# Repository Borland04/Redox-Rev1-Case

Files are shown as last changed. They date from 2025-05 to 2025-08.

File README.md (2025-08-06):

# Case for a Wireless Redox Rev1 Keyboard

Case for a [Redox keyboard](https://github.com/mattdibi/redox-keyboard/tree/master/redox) with Wristrest and Tenting, built from scratch but inspired by [Original Mattdibi Case](https://github.com/mattdibi/redox-keyboard/tree/master/redox/case), [Neodox Case](https://github.com/Pastitas/Redox-neo-Case) and [Ergodox Keyboard](https://ergodox-ez.com/).

This case is built for a **Wireless** Rev1 with use of [Nice!Nano V2](https://nicekeyboards.com/nice-nano/) MCU (Or its alternatives. In my case - [ProMicro NRF52840](https://www.elecrow.com/pro-micro-nrf52840-development-board-compatible-with-nice-nano-v2-0.html)).

**TL;DR:** [Assembly Guide](#assembly)

## Table of Contents
* [Bill of Materials](#bill-of-materials)
* [PCB Prerequisites](#pcb-prerequisites)
  * [Differences & Requirements](#differences--requirements)
* [Assembly](#assembly)
  * [Bottom](#bottom)
  * [Top](#top)
  * [Tenting](#tenting)
  * [Wrist Rest](#wrist-rest)
  * [Final Touches](#final-touches)
* [Contributions](#contributions)
* [To Be Done](#to-be-done)

---

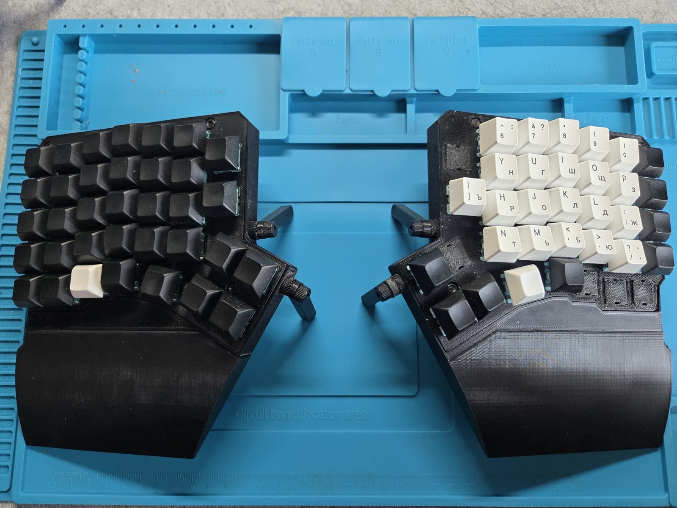
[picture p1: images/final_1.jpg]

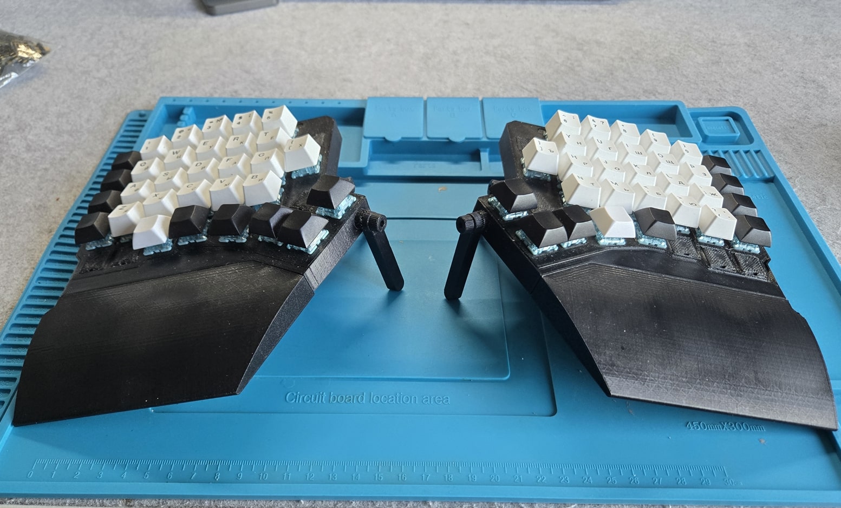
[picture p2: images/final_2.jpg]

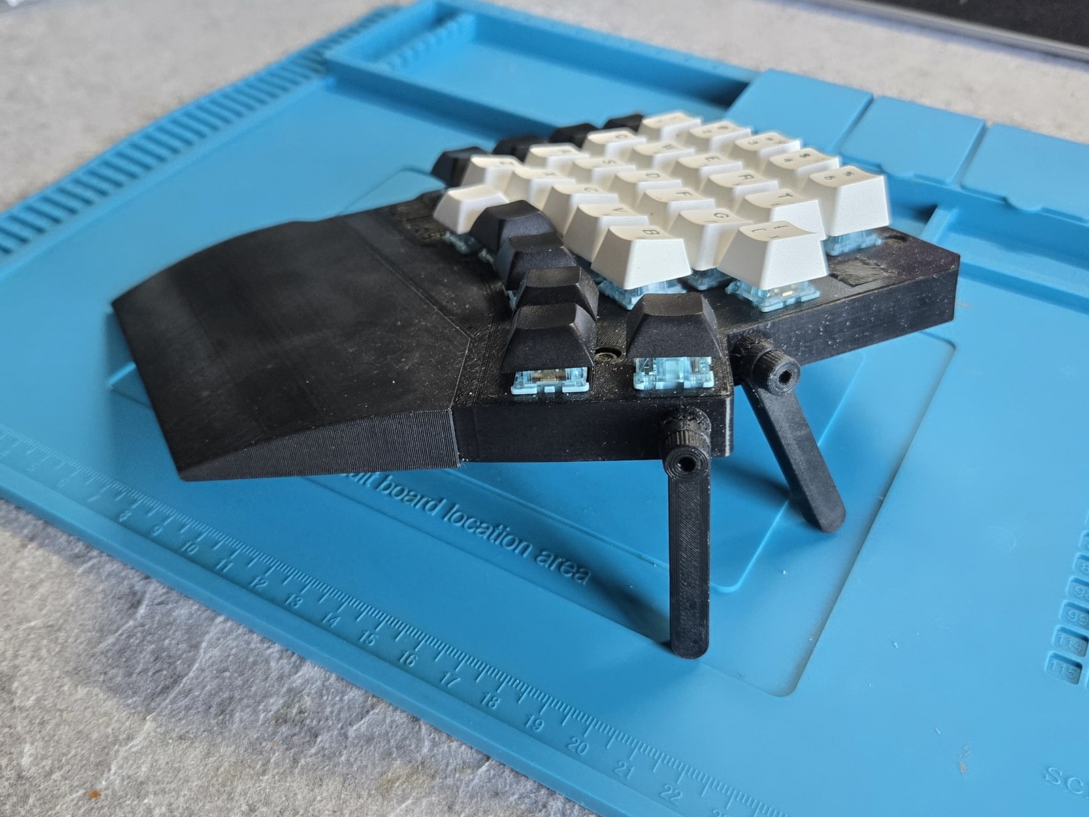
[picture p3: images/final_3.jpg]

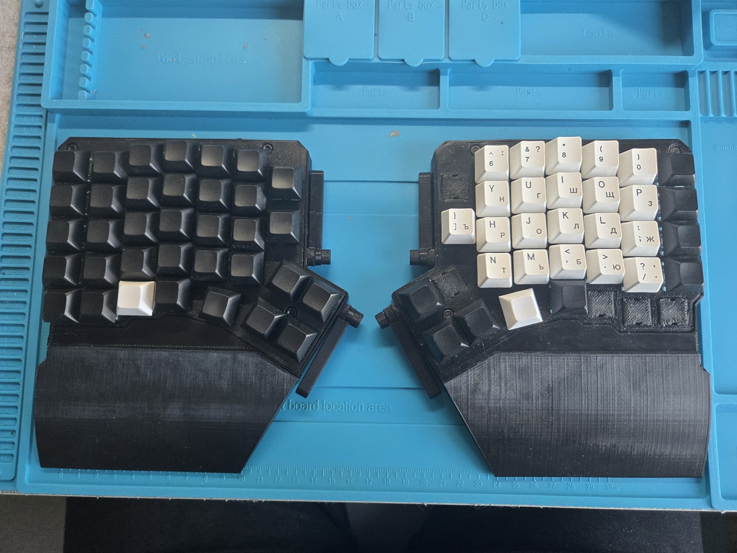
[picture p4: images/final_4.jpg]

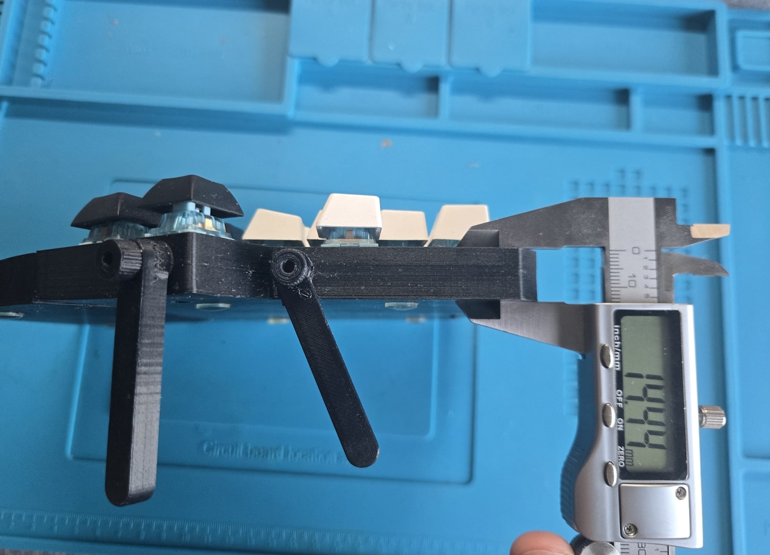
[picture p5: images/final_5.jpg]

> [!WARNING]
> +2mm if using `bottom_8mm` (which is preferred, because of right half's USB position. See [Assembly Guide](#assembly) for more info)

---
## Bill of Materials

| Item | Image | Quantity | Description |
| --- | --- | --- | --- |
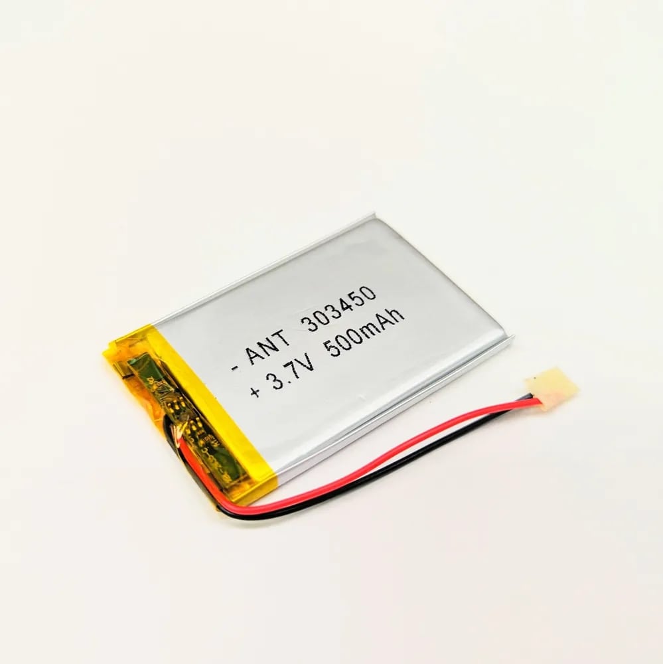
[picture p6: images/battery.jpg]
| LiPol 3.7V Battery 403040 or thinner (500 mAh). Might be thicker if using `bottom_8mm` |  | 2 | |
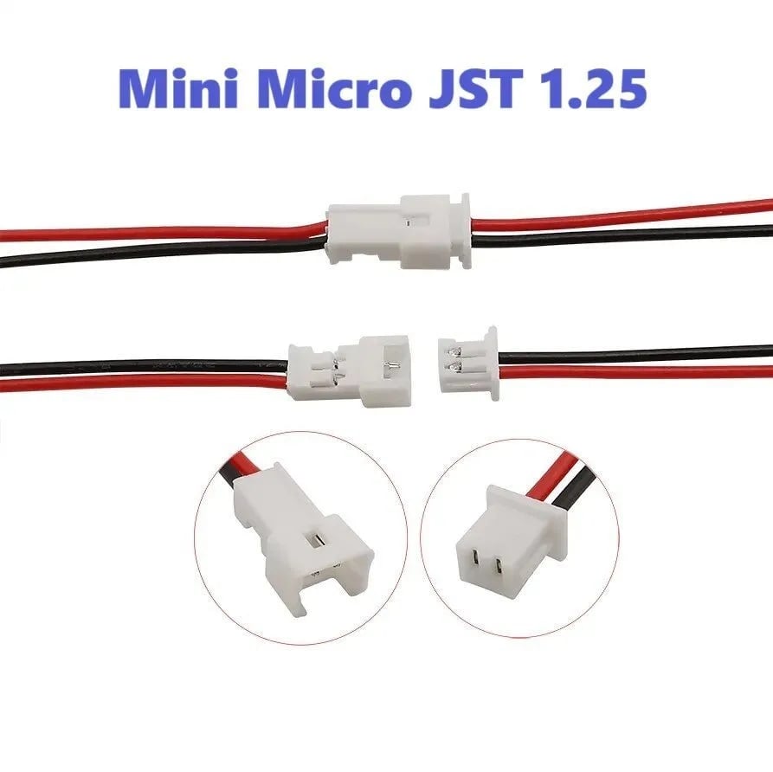
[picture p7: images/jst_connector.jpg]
| JST-XH PH 1,25 2-pin connectors |  | 2 pairs | Used to connect batteries to a PCBs<br><br>Part of a `PCB Prerequisites` |
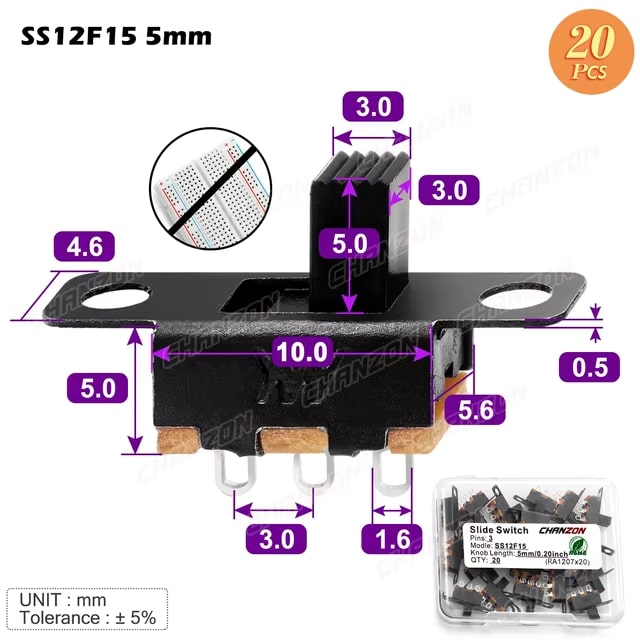
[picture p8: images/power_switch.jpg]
| Micro Slide Switch Spdt SS12F15 |  | 2 | [AliExpress](https://aliexpress.ru/item/1005003938856402.html?sku_id=12000027515454290)<br><br>Part of a `PCB Prerequisites` |
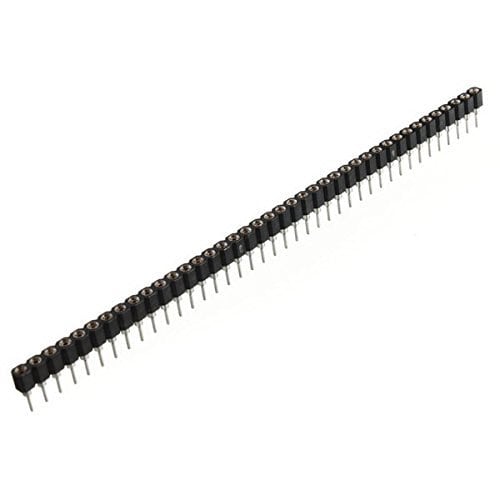
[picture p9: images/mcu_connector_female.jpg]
| MCU Hot-Swap Female connector |  | 48 pins | [Amazon](https://www.amazon.in/Single-Headers-Machine-Female-2-54mm/dp/B0187LTEX2)<br><br>Part of a `PCB Prerequisites` |
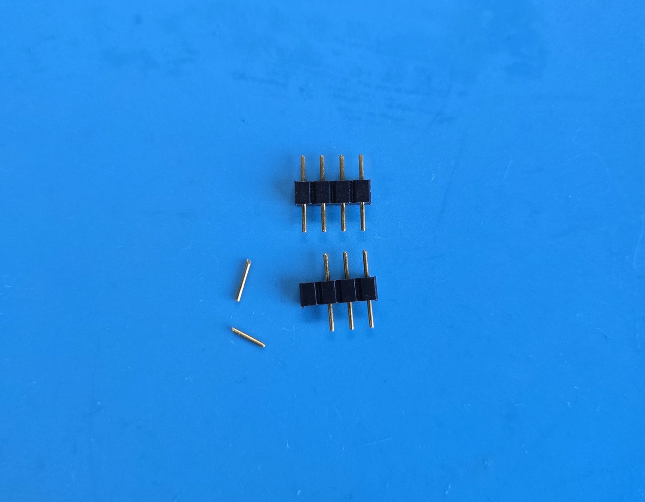
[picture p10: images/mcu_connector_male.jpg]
| RGB 4-pin Male connector<br> |  | 24 pins | [AliExpress](https://aliexpress.ru/item/1005006655092258.html?gatewayAdapt=glo2rus&sku_id=12000037934700782)<br>Remove plastic holder, cut each pin in two halves<br><br>Part of a `PCB Prerequisites` |
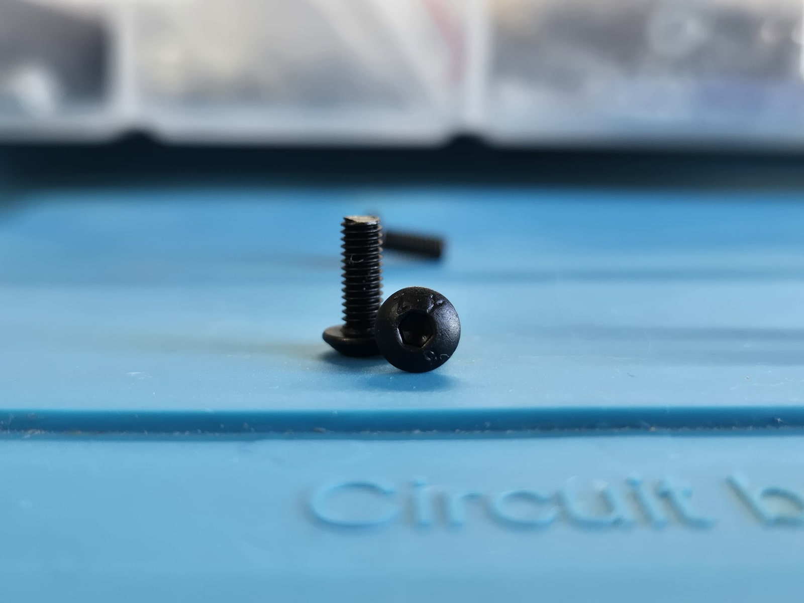
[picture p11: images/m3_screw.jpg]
| M3x8 Screw<br> |  | 12 | Used in a tight space. Use Hex or Phillips screws. Do not use screws made for a wrench. |
| M3x2.5 Nut | | 12 (14 with Wrist Rest) | |
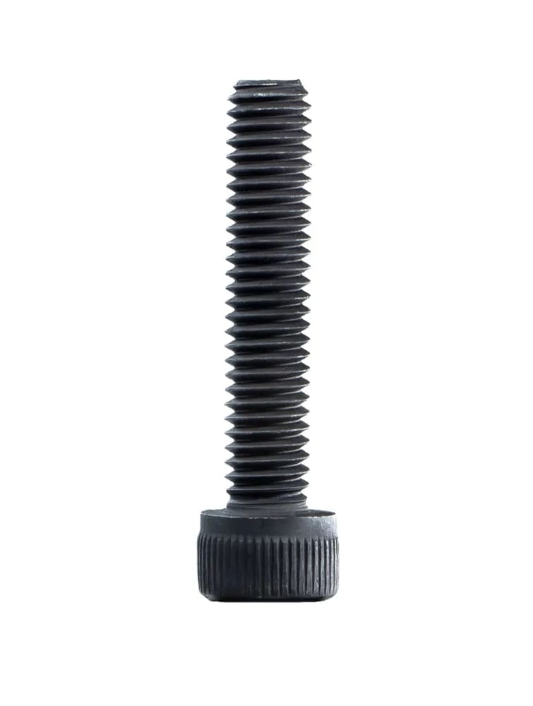
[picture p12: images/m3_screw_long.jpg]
| M3x16 Screw<br> |  | 0 (2 with Wrist Rest) | Used only in a Wrist Rest |
| M2 Nut | | 2 | Used to fix Power Switch |
| M2x4 Screw | | 2 | Used to fix Power Switch. Can be longer. |
| Hot Glue | | - | Need a few places, to fix some elements. Can be done without it, but not recommended. |
| Silicon pads 9x1.5 (Or thicker if you want) | | 8 (12 with Wrist Rest)  | |

## PCB Prerequisites

> [!WARNING]
> Guide below assumes you have assembled PCB.
> This section describes how my PCB looked like when I did assemble the case.
> Minor differences should be fine, but case was only tested with described PCB.

Original PCB assembly guide: https://github.com/mattdibi/redox-keyboard/tree/master/redox#assembly-guide

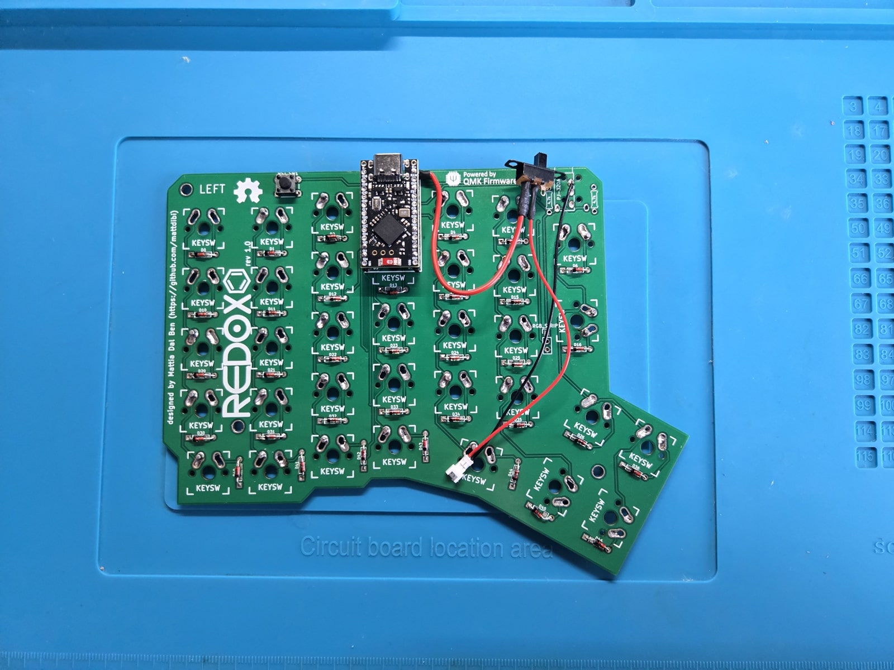
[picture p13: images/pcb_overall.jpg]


---

#### Differences & Requirements:

* PCB must have Hot-Swappable switches (see https://github.com/mattdibi/redox-keyboard/tree/master/redox#hot-swappable-switches) - required by `Top` part of the case. *You can workaround this requirement by extending "switch holes" on a `Top` part* 

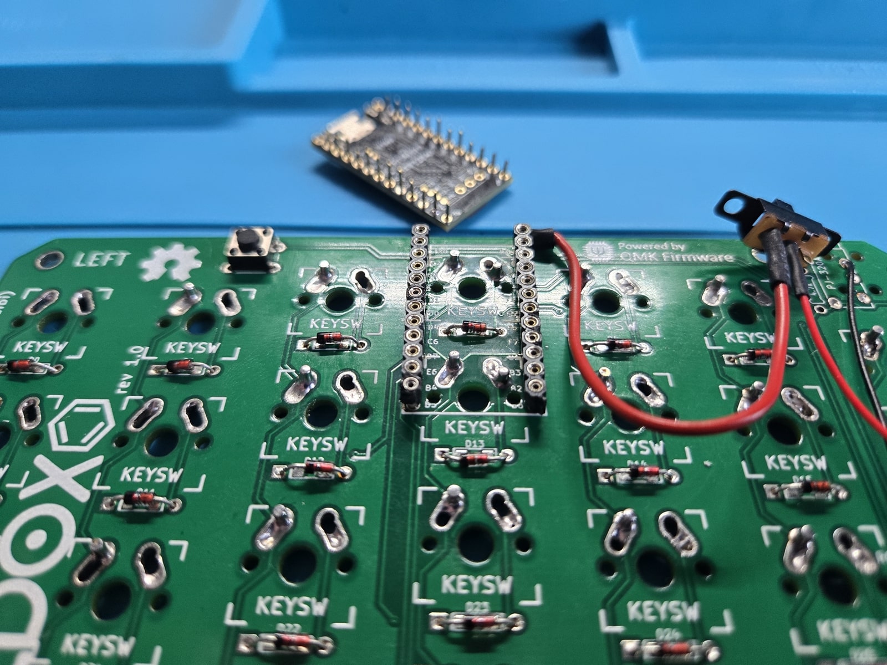
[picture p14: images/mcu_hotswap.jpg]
* I also made a Nice!Nano MCU hot-swappable. 

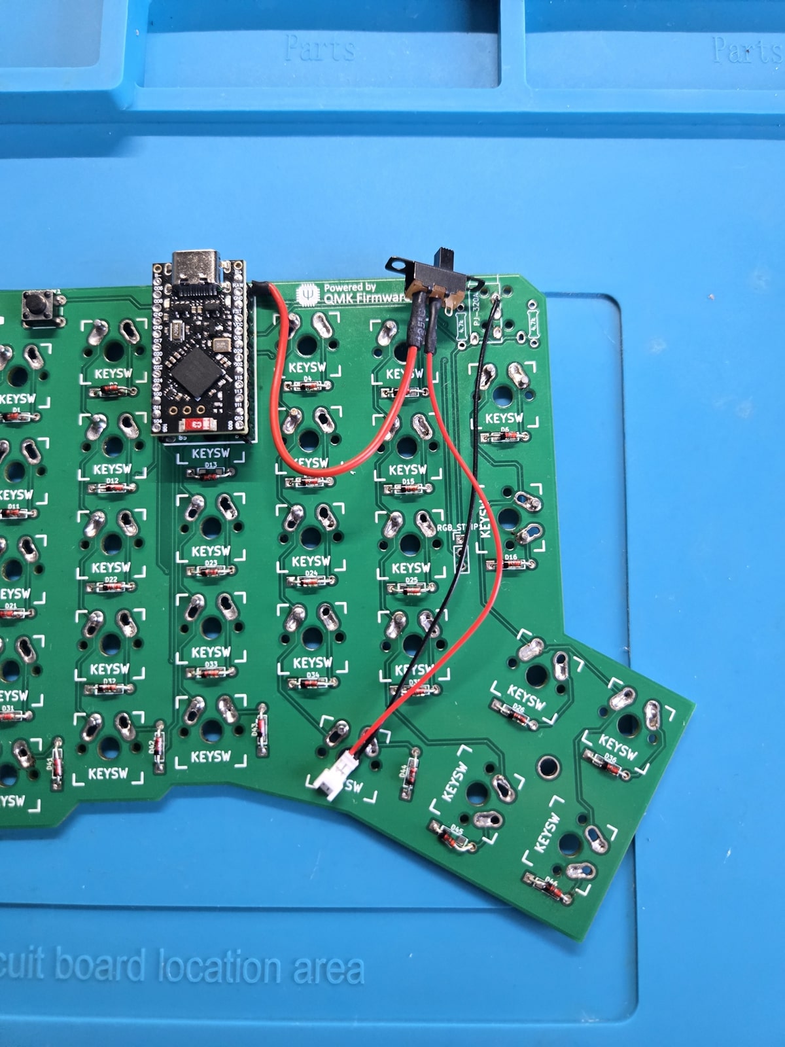
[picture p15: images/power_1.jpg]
* Solder 2-pin battery connector with power switch, breaking a `+` wire. 
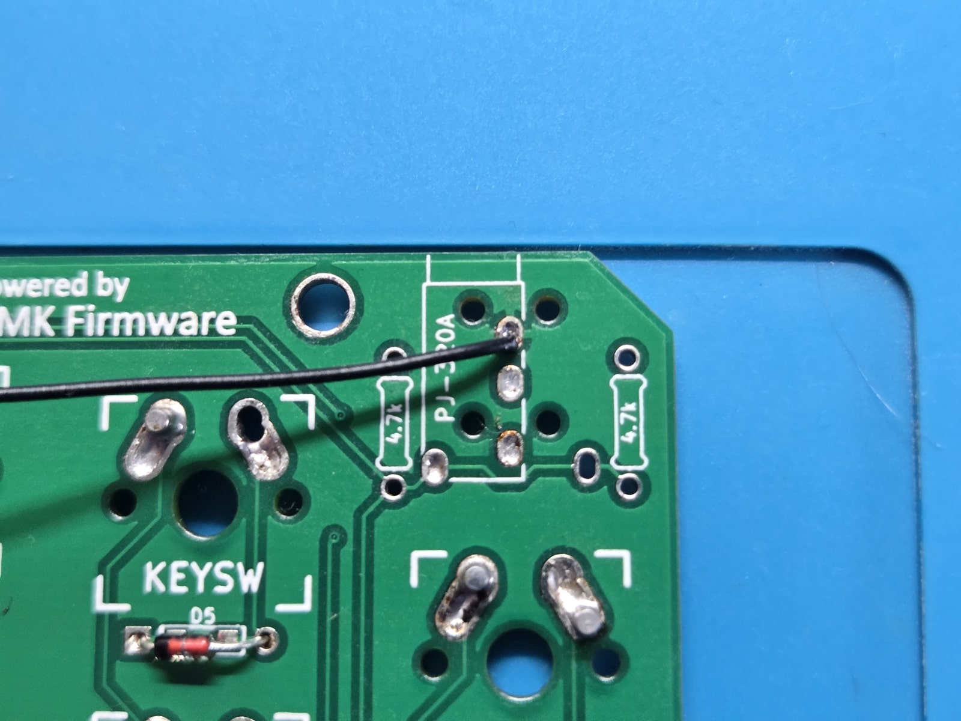
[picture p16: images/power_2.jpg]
	* `-` wire should be soldered to a `ground` (or `Battery-` if you prefer). I choose this convenient place: 
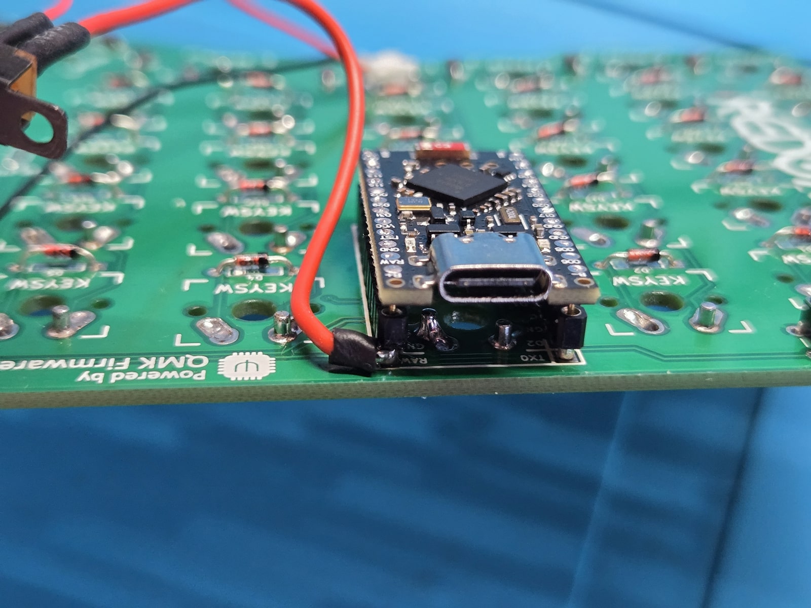
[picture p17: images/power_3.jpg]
	* `+` wire should be soldered to a `Raw` (or `Battery+` if you prefer) pin of MCU: 

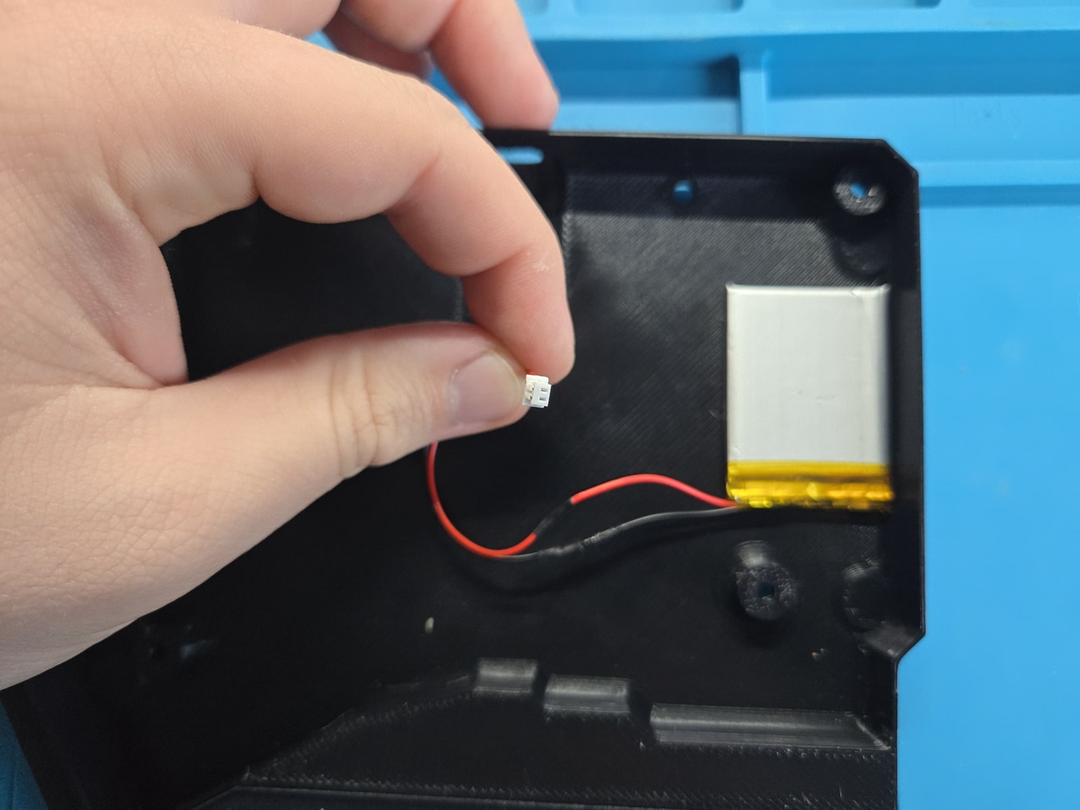
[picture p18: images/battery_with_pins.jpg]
* Solder 2-pin connector to a batteries: 

## Assembly

> [!NOTE]
> Following instructions describes assembly of one half. Since Redox halves are symmetric, these instructions are applied to another half as well, with only one requirement - printed models should be mirrored.

Total printed parts to assemble **one half**:
* `Bottom.stl` - 1 pcs;
* `Top.stl` - 1 pcs;
* `Wristrest.stl` - 1 pcs;
* `Reset_button.stl` - 1pcs;
* `Tent_leg.stl` - 2 pcs (1 + 1 mirrored);
* `Tent_knob.stl` - 2 pcs.

---
#### Bottom

> [!TIP] 
> You can build the case WITHOUT a Wristrest. For that, you need to hide `Bottom -> Bodies -> 'Wristrest base'` body in a source project (`.f3z` - Fusion 360 project).

> [!WARNING]
> Asymmetric USB port problem. Expand to see more
<details>
<summary>Asymmetric USB port problem</summary>
	
> Nice!Nano was asymmetrical USB port. Because of that, RIGHT half might not fit into the case.
> Possible solutions:
>   * Print RIGHT `Bottom.stl` 2.5 mm thicker;
>   *  Heat bottom, where USB port will be located and deform it a little (See pics below).
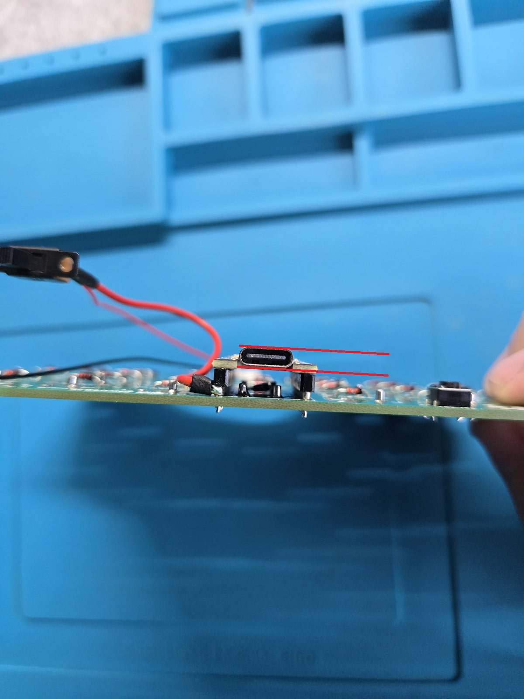
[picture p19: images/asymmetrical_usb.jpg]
>      
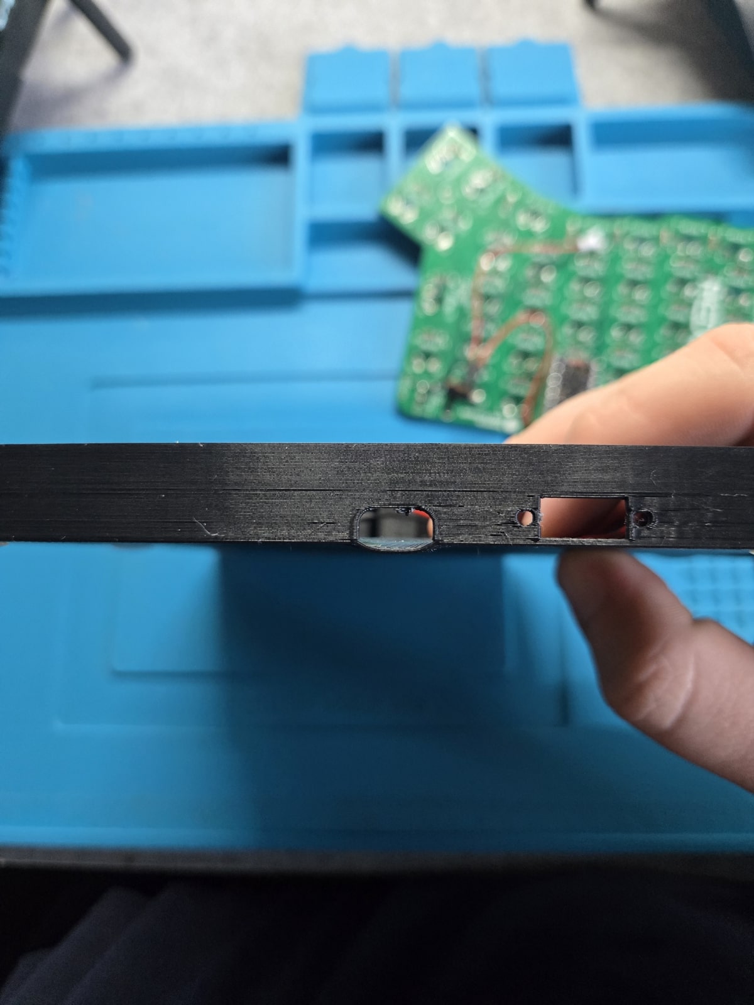
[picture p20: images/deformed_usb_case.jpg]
>      
</details>

* Print **one** `Bottom.stl`.
* Print **one** `Reset_button.stl`.
* Use drop of a Hot Glue to fix the battery in place. *Position is not important, I just prefer it at the outer side.* 
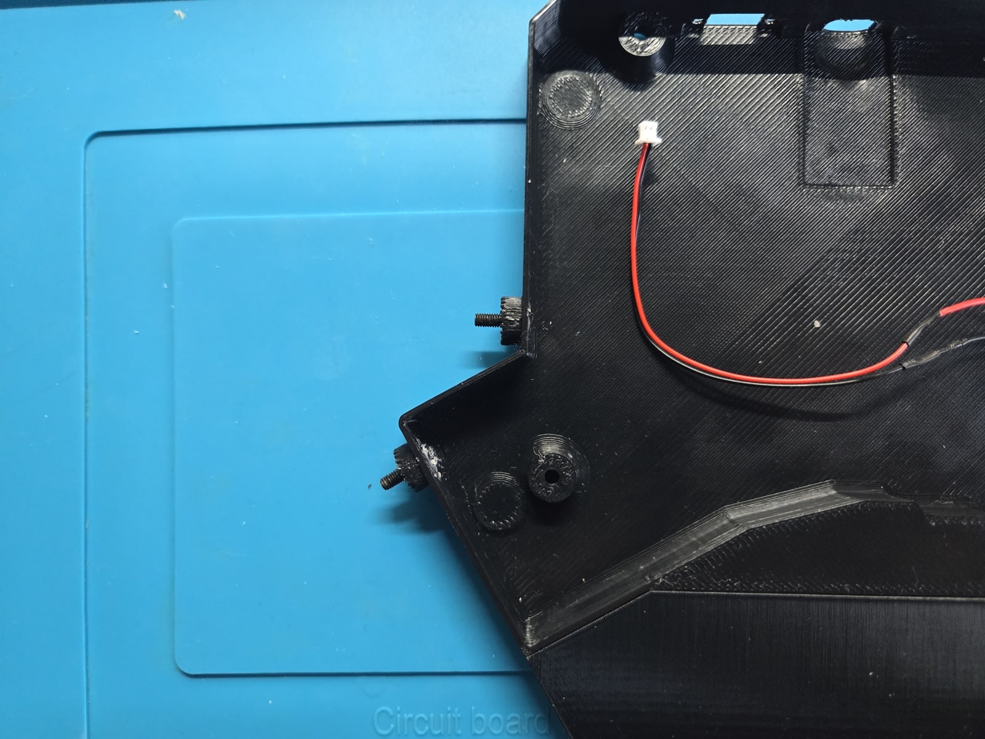
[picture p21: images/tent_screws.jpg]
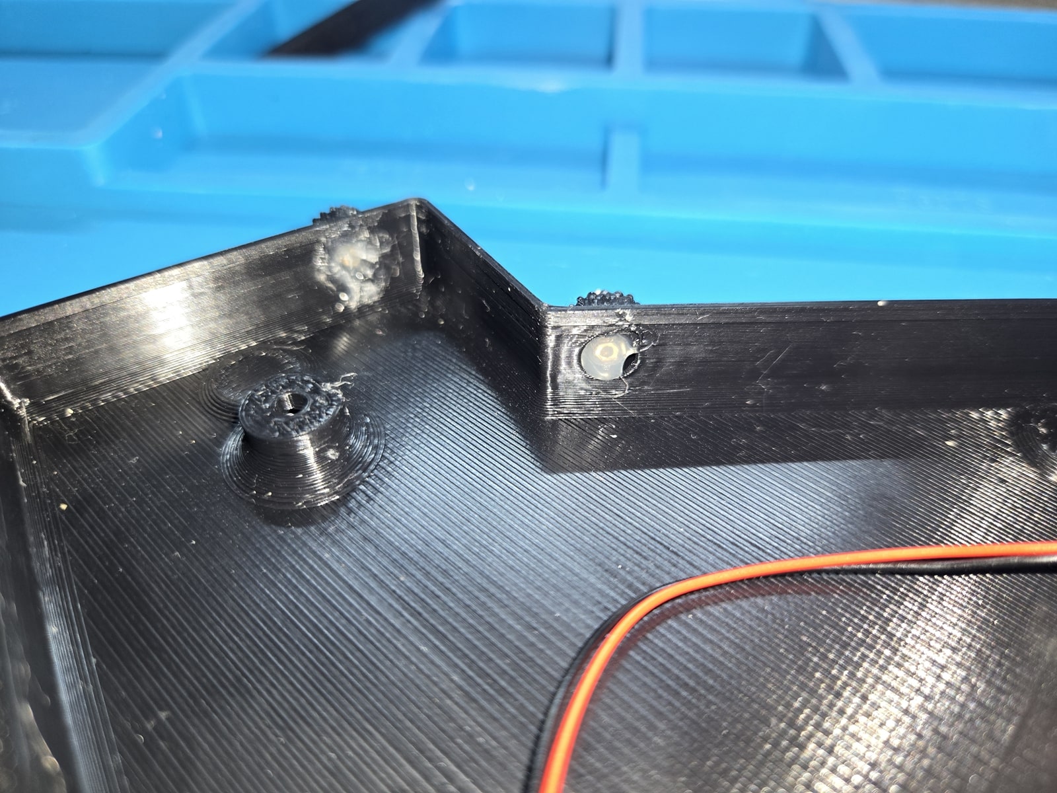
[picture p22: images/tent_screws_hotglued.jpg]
* Put `M3 Screws` in a tenting base. Fill remaining space with a hot glue. *Using hot glue is highly recommended - otherwise you'll have hard times putting knobs on that screw.*  

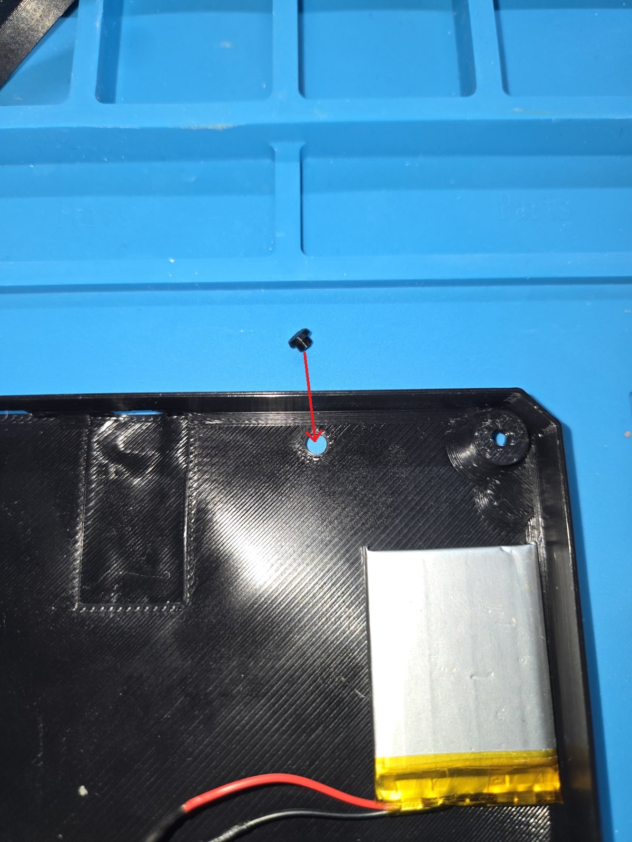
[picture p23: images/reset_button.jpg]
* Put `Reset button` in according slot. 

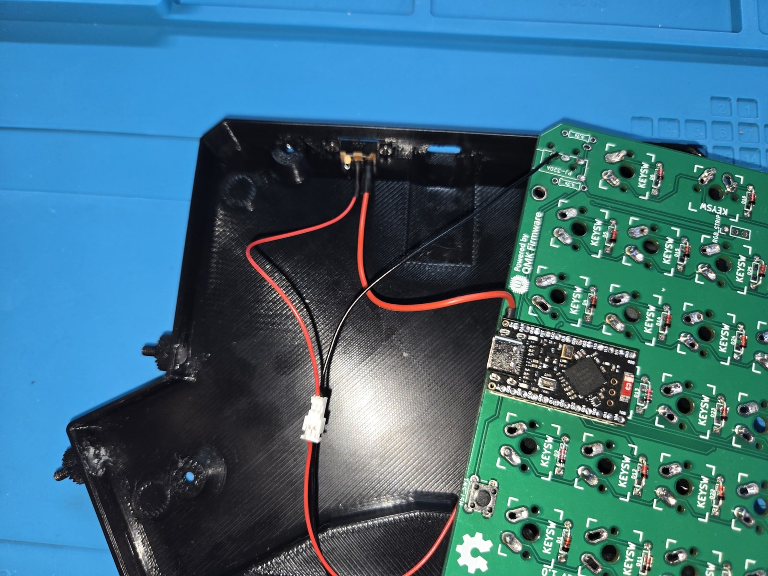
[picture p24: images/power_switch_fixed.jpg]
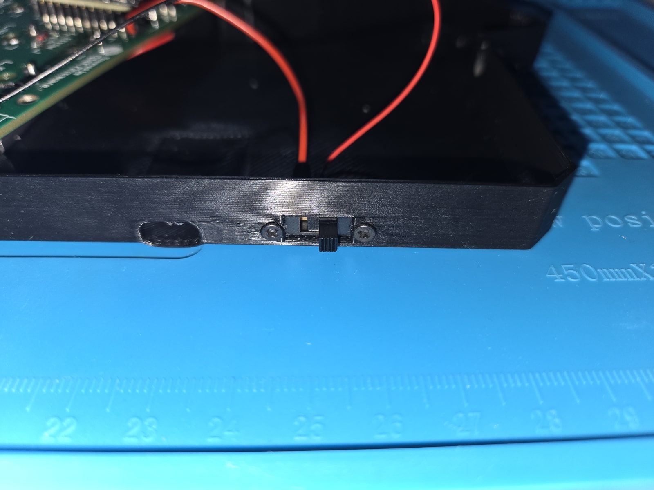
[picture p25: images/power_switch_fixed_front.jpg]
* Put the `Power Switch`, which is a part of the PCB, in according slot. Fix it using `two M2 screws` and `two M2 nuts`.  

* Connect battery to a PCB.
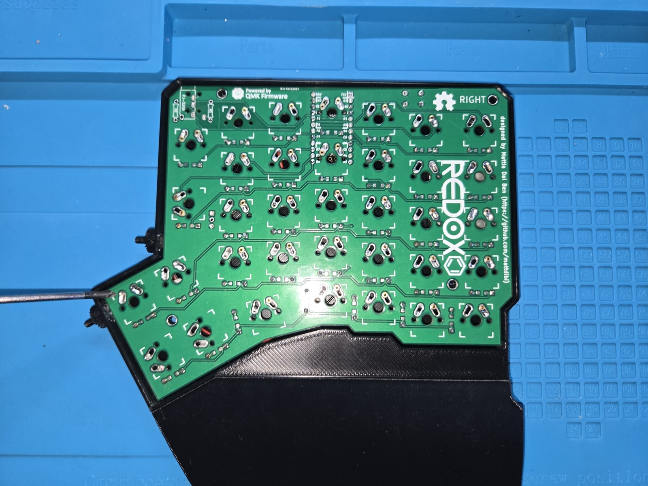
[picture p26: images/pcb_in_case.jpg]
* Place the PCB. 

---
#### Top

* Print **one** `Top.stl`.

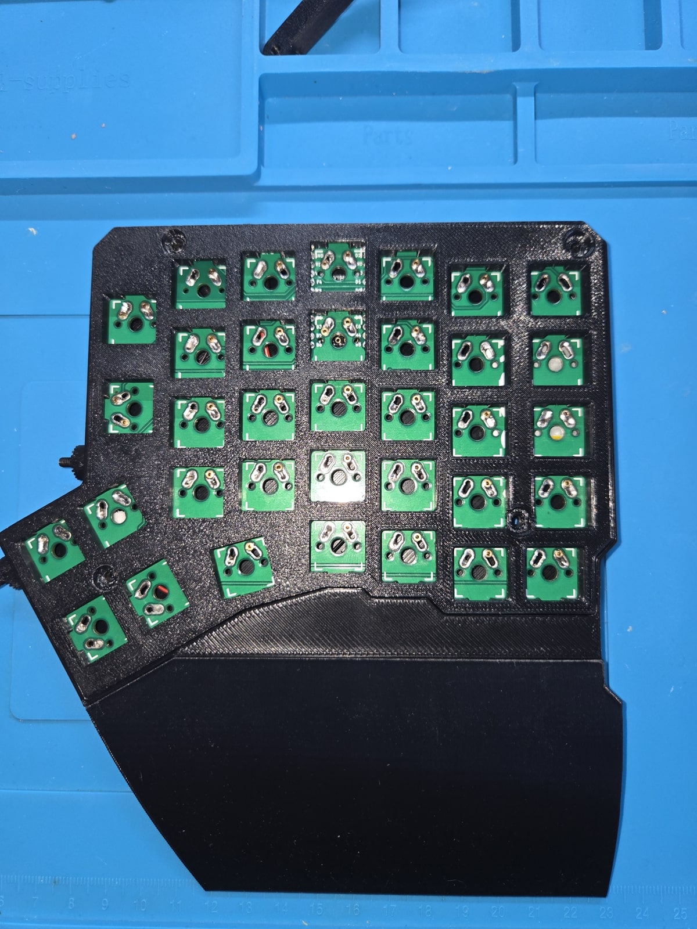
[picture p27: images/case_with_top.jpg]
* Place `Top` on top of a PCB, closing the case. 
* Screw the case using `four M3 screws` and `four M3 nuts`. I suggest to put `M3 nuts` in a `Top` holes.

Now you can finish the keyboard by adding `Switches` and `Keycaps`.

---
#### Tenting

* Print **two** `Tent_leg.stl`: one - as is, another - optionally mirrored.
* Print **two** `Tent_knob.stl`.

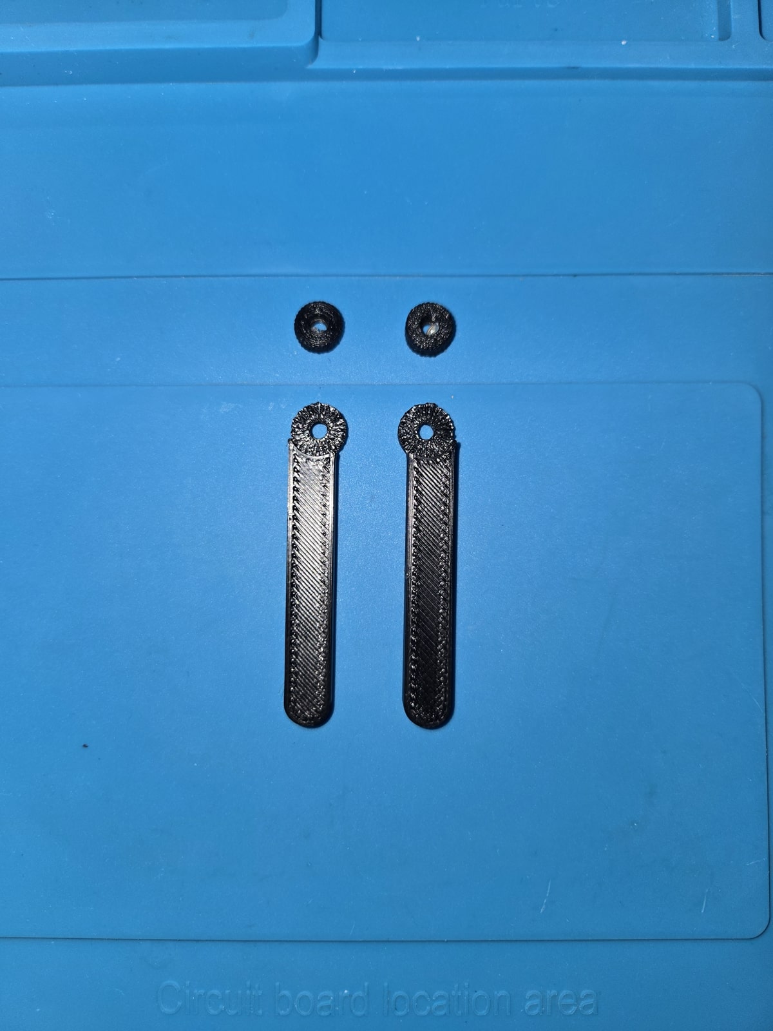
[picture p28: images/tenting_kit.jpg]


* Take `two M3 Nuts` and place them into the `Tent_knobs`. Optionally, glue them (Usually not required - it depends on a printer tolerance).

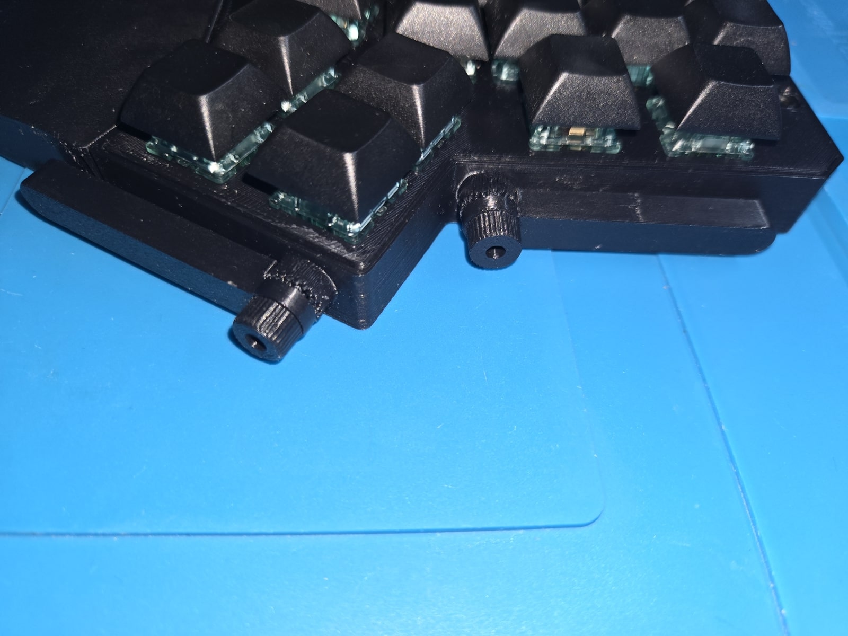
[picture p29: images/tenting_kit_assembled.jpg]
* Take `Tent_legs` and place them accordingly. Fix them using `Tent_knobs`. 

---
#### Wrist Rest

* Print **one** `Wristrest.stl`. See the picture below for a suggested slicing. Tree support is **highly recommended** - with `Normal Support` it is almost impossible to clean a nut slot.
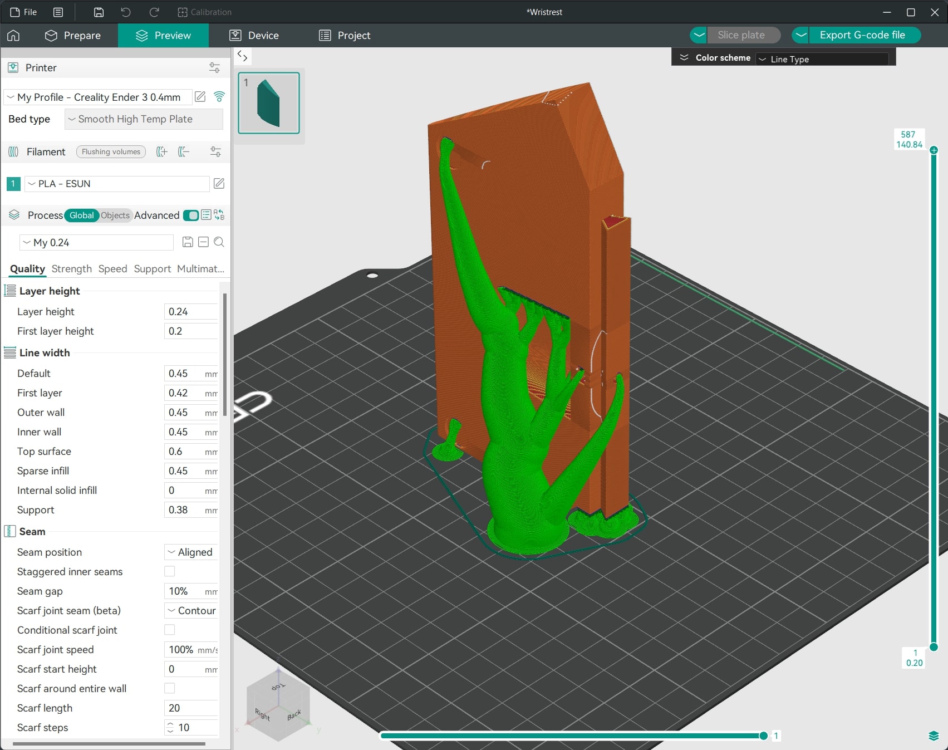
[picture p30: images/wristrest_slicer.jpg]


* Put `one M3 Nut` in a nut slot.
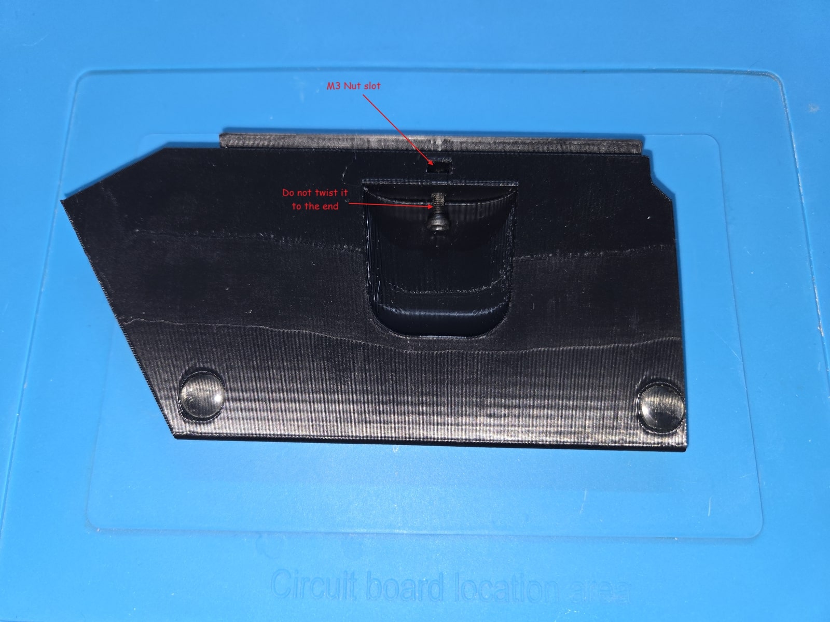
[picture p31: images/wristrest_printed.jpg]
* Take `one Long M3 Screw` and screw it. 

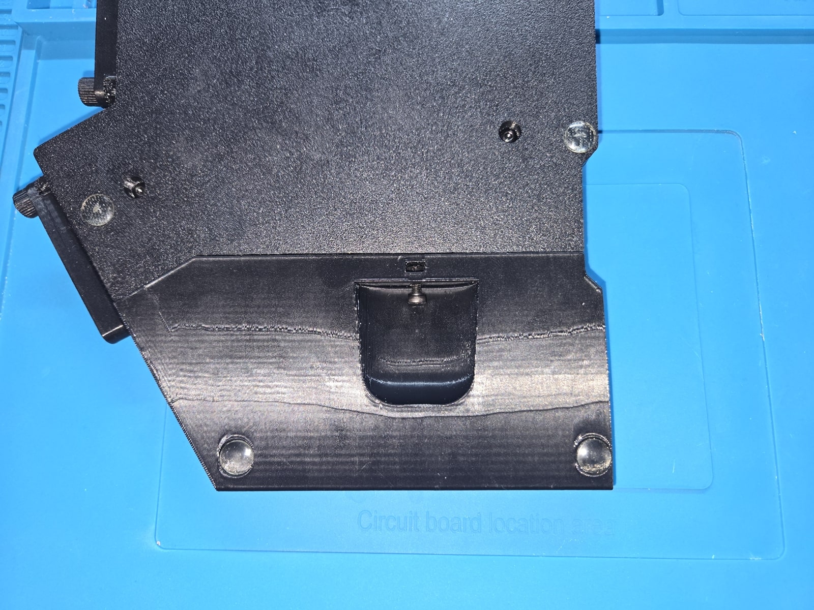
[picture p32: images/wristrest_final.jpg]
* Slide `Wristrest` into the `Wristrest base`. To fix the Wristrest, twist the screw to the end. 

---
#### Final touches

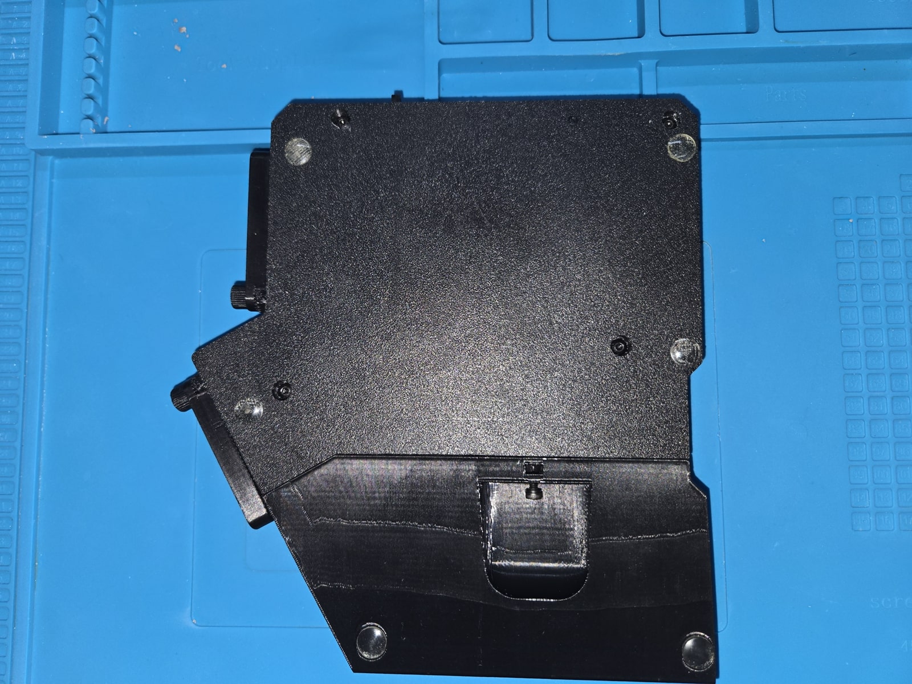
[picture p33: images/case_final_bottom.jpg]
* Glue silicon pads in according slots 

## Contributions

I am just a guy, who is quite far from a professional CAD user, so I appreciate any advice/contribution/remix.

I tried to introduce some parameters in model, but there is a big chance they are not working properly (See [To Be Done](#to-be-done) section).

## To Be Done

* Test and fix the model parameters - IDK if changing current parameters won't break whole model;
* Less thickness between M3 screw & nut, which are fixing top & bottom parts (-1mm - -2mm)
* Check the possibility to use M3 instead of M2 for a Power Switch;
* Make case thinner: move battery into the wristrest + check how to make a thinner hot-swappable MCU. Approx. thickness reduction: 2.5-3mm;
* <?> Adapt model to a **Wired** Redox.

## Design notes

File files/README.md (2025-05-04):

# STLs
### Bottom
* `bottom.stl` - original part with total thickness 14.5mm (empty space between PCB and part's floor - **6mm**)
* `bottom_8mm.stl` - increased empty space from 6 to **8mm**

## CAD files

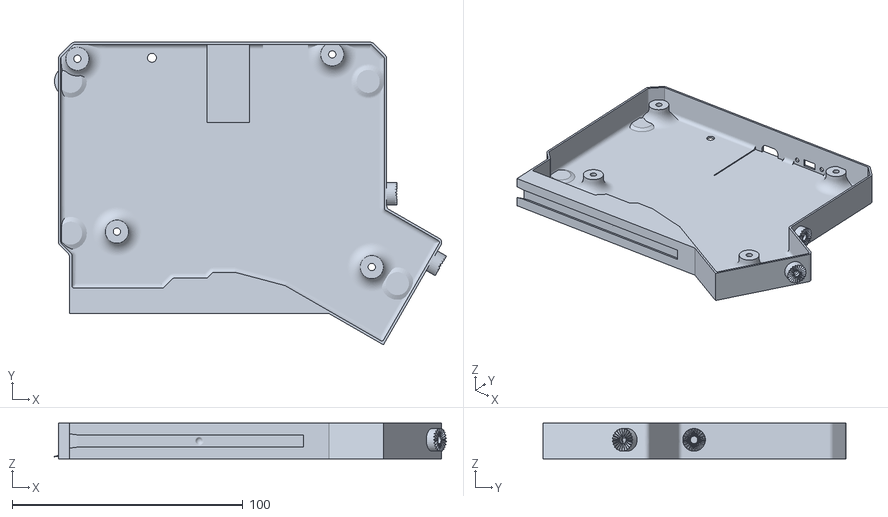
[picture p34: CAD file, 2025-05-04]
files/stls/bottom_8mm.stl
169.9 x 131.2 x 15.6

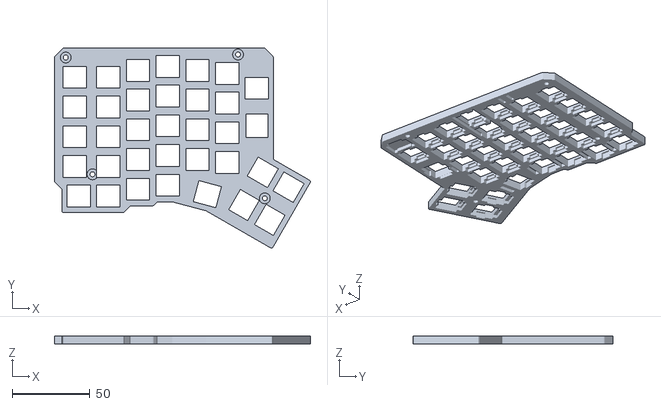
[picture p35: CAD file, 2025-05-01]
files/stls/top.stl
164.2 x 128.5 x 5.00

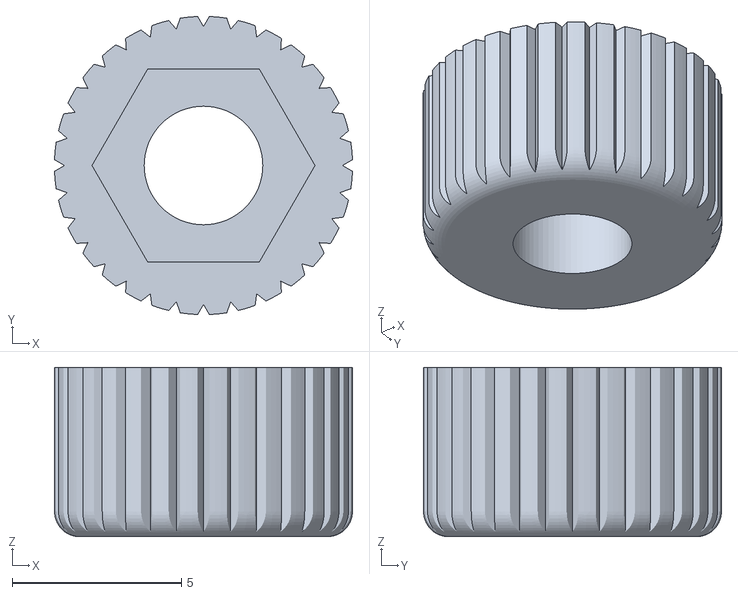
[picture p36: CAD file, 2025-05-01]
files/stls/tent_knob.stl
8.79 x 8.79 x 5.00

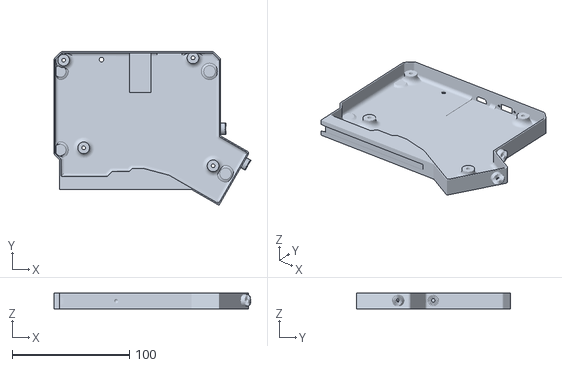
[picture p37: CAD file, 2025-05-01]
files/stls/bottom.stl
168.2 x 131.2 x 13.6

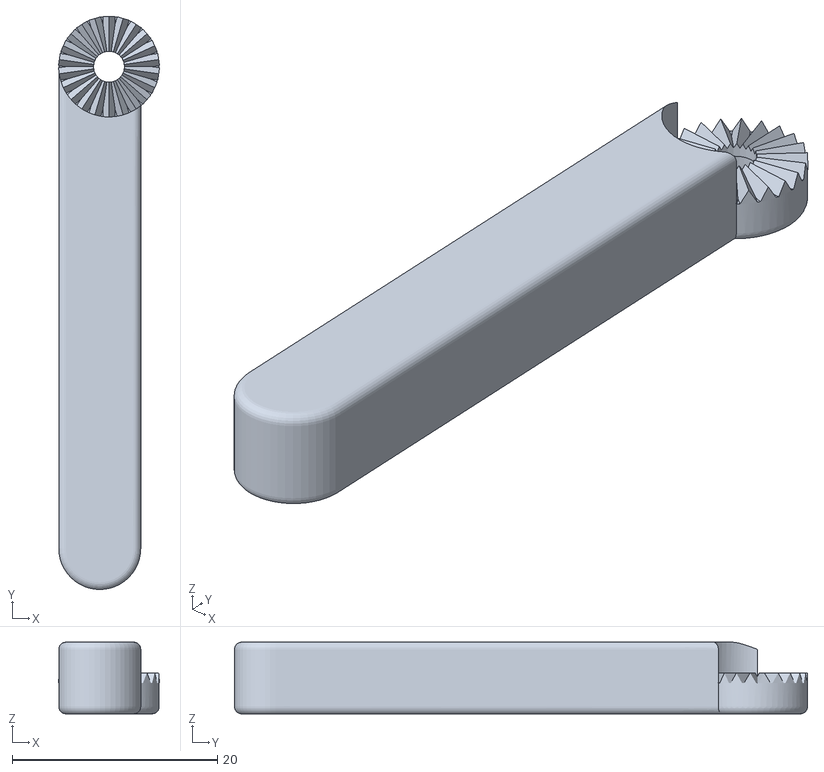
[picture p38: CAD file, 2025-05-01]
files/stls/tent_leg.stl
9.87 x 55.9 x 7.00

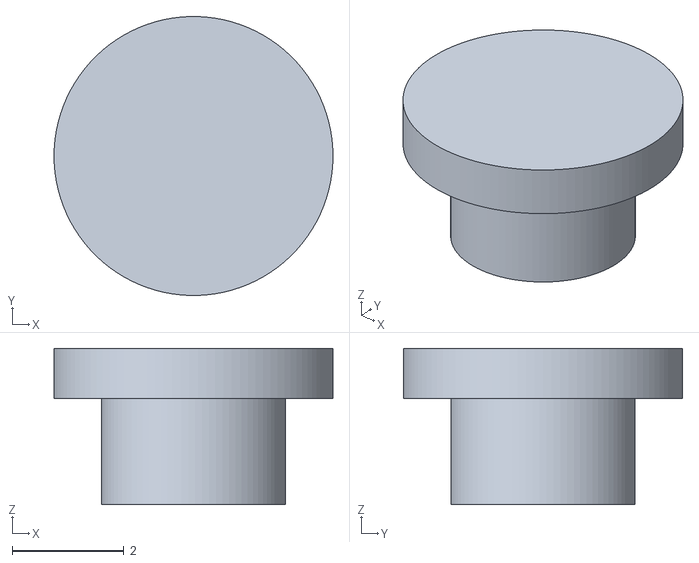
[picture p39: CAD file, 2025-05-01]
files/stls/reset_button.stl
5.00 x 5.00 x 2.80

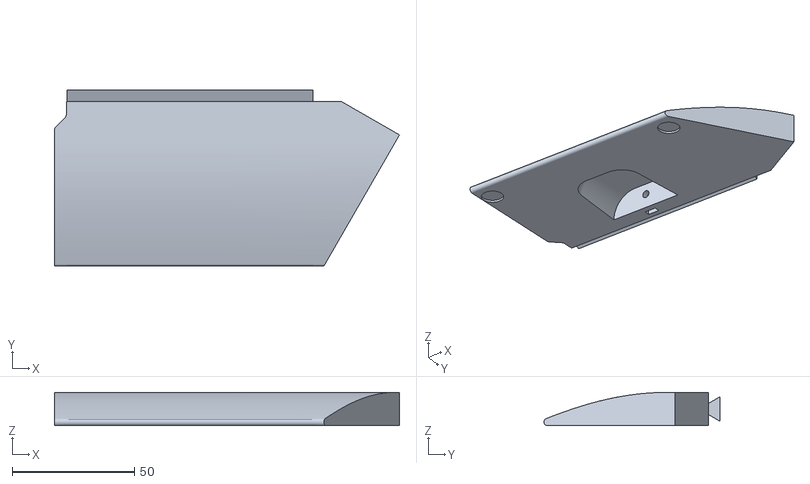
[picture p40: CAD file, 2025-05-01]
files/stls/wristrest.stl
140.9 x 72.0 x 13.6

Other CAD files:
files/case.f3z

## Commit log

2025-05-01 Add fusion project + STL files
    [bottom.stl, case.f3z, reset_button.stl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]
2025-05-01 Update files hierarchy
    [bottom.stl, reset_button.stl, tent_knob.stl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]
2025-05-01 Update BOM - move images into separate column
2025-05-04 Add "thick" bottom - with empty space 8mm
    [bottom_8mm.stl]
2025-05-04 Update project - now it should be fine to change most of parameters
    [case.f3z]
